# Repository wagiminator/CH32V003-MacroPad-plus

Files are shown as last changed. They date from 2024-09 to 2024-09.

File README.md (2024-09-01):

# MacroPad plus based on CH32V003
The MacroPad plus is a versatile extension for your keyboard that has six programmable keys and a rotary encoder knob. These buttons and the knob can be configured to perform a variety of actions, such as triggering specific key combinations or mouse movements. You can easily modify the firmware used to operate the MacroPad to suit your needs.

Each button and knob on the MacroPad also has addressable LEDs (NeoPixels), which can be programmed in the same way as the keys. This lets you customize the colors, patterns, or animations of your device.

Connecting the MacroPad to your PC is easy - simply plug it in via USB. It's immediately recognized by your PC as an HID composite device, so no special drivers are needed. This makes the MacroPad a user-friendly and accessible option for anyone looking to enhance their keyboard's capabilities.

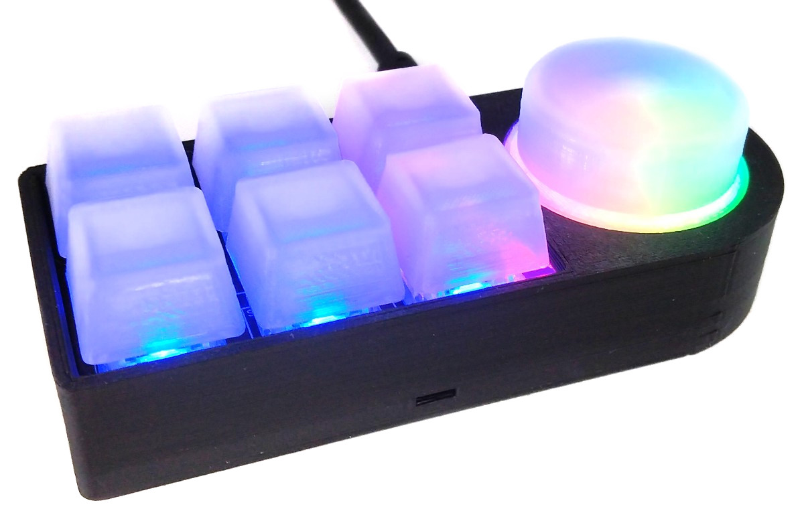
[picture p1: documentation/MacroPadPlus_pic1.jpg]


# Hardware
## Schematic
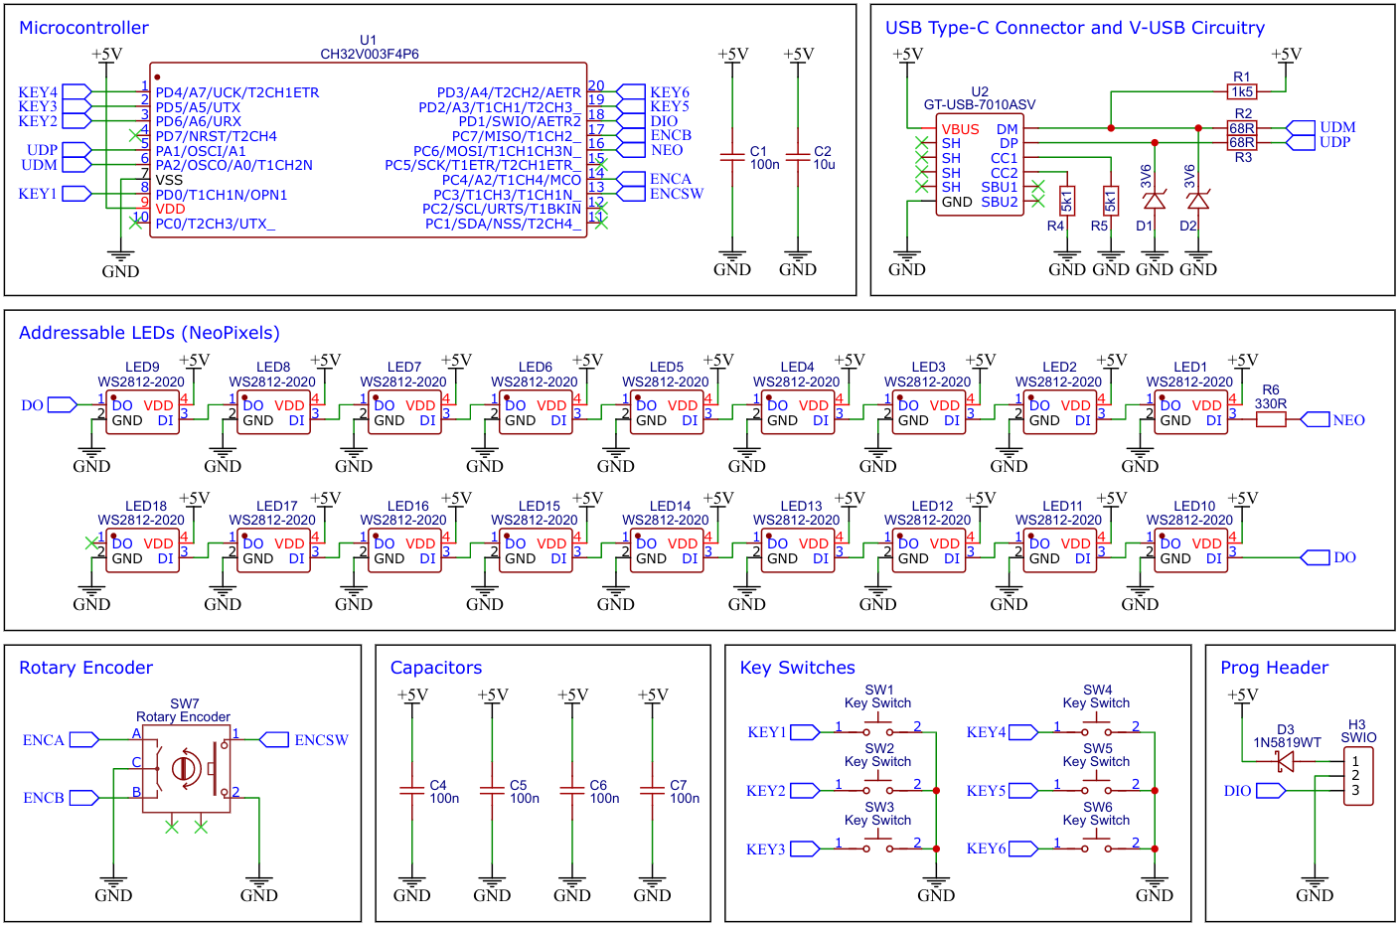
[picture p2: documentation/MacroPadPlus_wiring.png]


## The CH32V003 Family of 32-bit RISC-V Microcontrollers
The CH32V003 series is a collection of industrial-grade general-purpose microcontrollers that utilize the QingKe RISC-V2A core design supporting the RV32EC instruction set. These microcontrollers are equipped with various features such as a 48MHz system main frequency, 16KB flash, 2KB SRAM, 2.7V - 5.5V supply voltage support, a single-wire serial debug interface, low power consumption, and an ultra-small package. Additionally, the CH32V003 series includes a built-in set of components including a DMA controller, a 10-bit ADC, op-amp comparators, multiple timers, and standard communication interfaces such as USART, I2C, and SPI.

## Buildung Instructions
1. Take the Gerber files (the *zip* file inside the *hardware* folder) and upload them to a PCB (printed circuit board) manufacturer of your choice (e.g., [JLCPCB](https://jlcpcb.com/)). They will use these files to create the circuit board for your device and send it to you.
2. Once you have the PCB, you can start soldering the components onto it. Use the BOM (bill of materials) and schematic as a guide to make sure everything is connected correctly. You can find the corresponding files in the *hardware* folder.
3. Upload the firmware by following the instructions in the next section (see below).
4. To create the case for your device, use the *stl* files in the *3dprint* folder with your 3D printer. Make sure to use transparent filament for the keycaps, knob, and ring.
5. After printing, secure the PCB to the bottom of the case using three self-tapping M2x5mm screws.
6. Next, glue the ring from the bottom into the circular recess in the top of the case.
7. Finally, assemble the case. Place the keycaps onto the switches and the knob onto the rotary encoder. Your device is now ready to use!

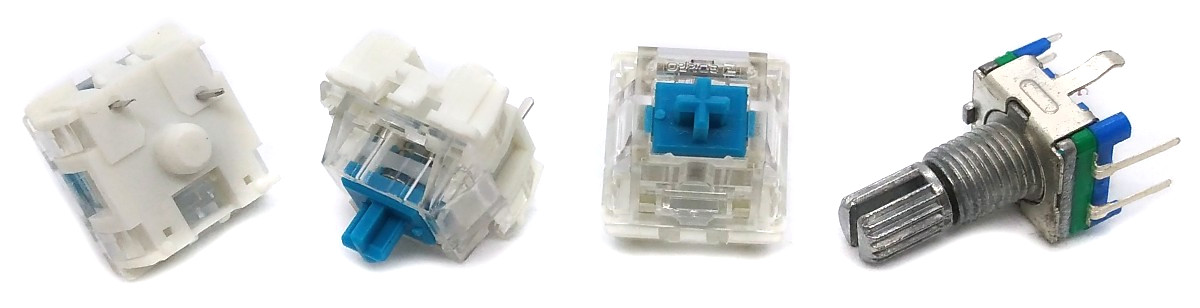
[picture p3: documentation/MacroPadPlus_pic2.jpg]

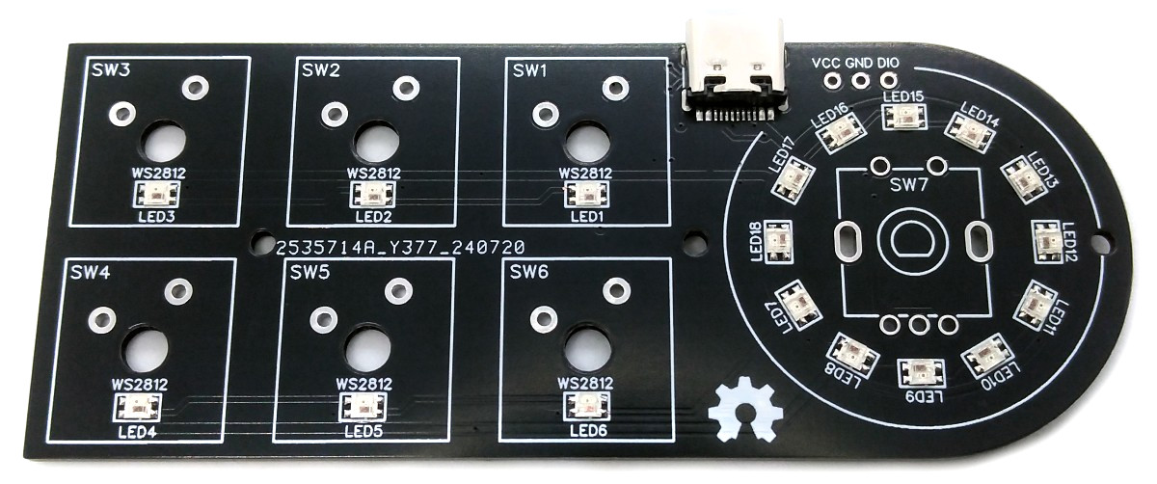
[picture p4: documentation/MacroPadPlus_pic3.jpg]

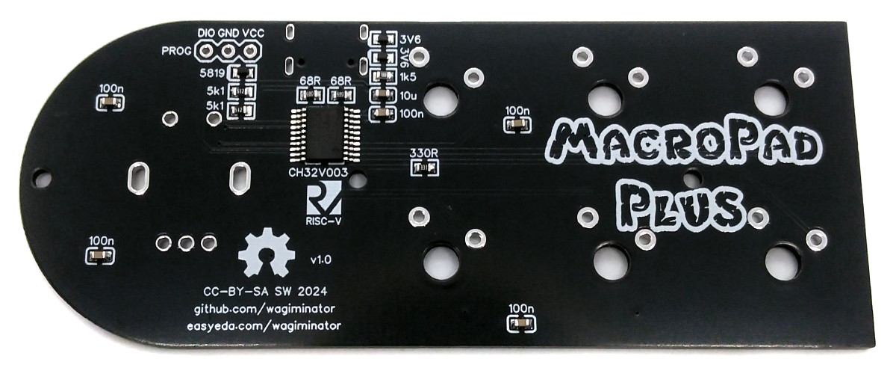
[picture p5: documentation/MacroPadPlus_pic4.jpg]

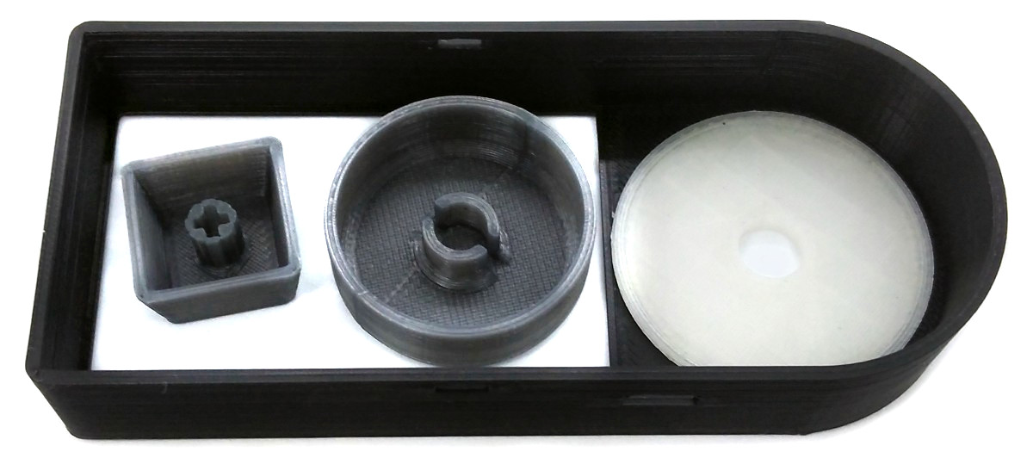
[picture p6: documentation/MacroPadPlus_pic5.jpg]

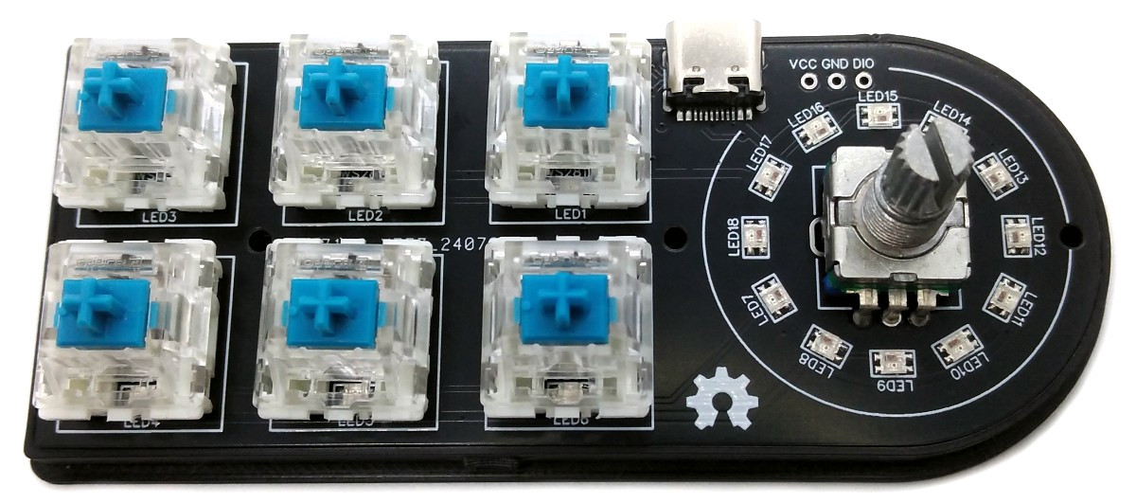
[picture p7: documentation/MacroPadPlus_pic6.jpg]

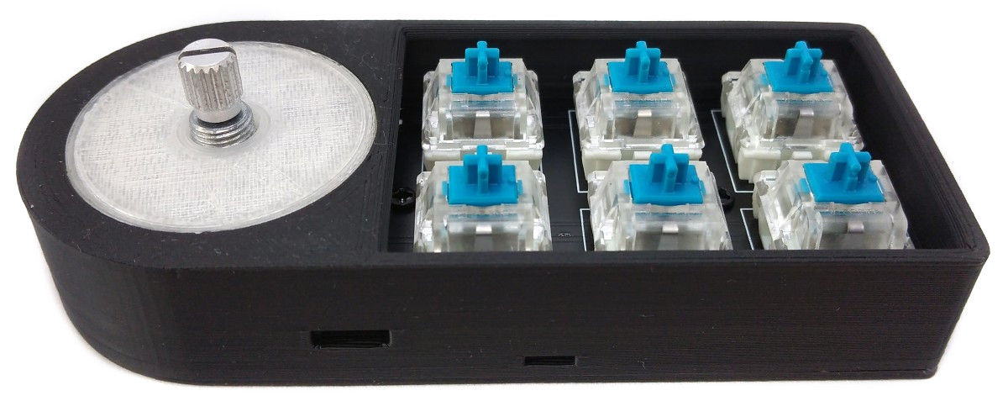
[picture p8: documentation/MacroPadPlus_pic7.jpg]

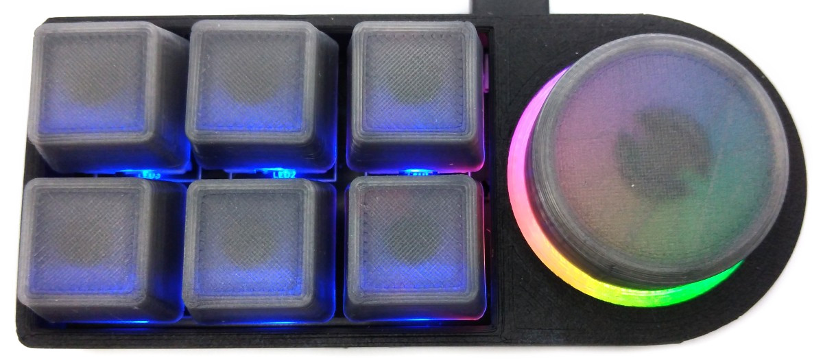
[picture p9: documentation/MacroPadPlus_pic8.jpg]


# Software
## Software USB
Since the CH32V003 lacks a hardware USB peripheral, USB functionality is handled in software. Charles Lohr's excellent implementation, [RV003USB](https://github.com/cnlohr/rv003usb), is used for this. It emulates a USB low-speed device using pin-change interrupts and bit-banging, with assembly code for the low-level protocol and some C code for higher-level functionality.

## Customizing the Firmware
The definition of the macros and their assignment to individual key events is done by editing the *macros.h* accordingly, which allows maximum freedom and flexibility. This file is commented in such a way that it should be possible to make adjustments even with basic programming skills.

## Programming and Debugging Device
To program the CH32V003 microcontroller, you will need a special programming device which utilizes the proprietary single-wire serial debug interface (SDI). The [WCH-LinkE](http://www.wch-ic.com/products/WCH-Link.html) (pay attention to the "E" in the name) is a suitable device for this purpose and can be purchased commercially for around $4. This debugging tool is not only compatible with the CH32V003 but also with other WCH RISC-V and ARM-based microcontrollers.



To use the WCH-LinkE on Linux, you need to grant access permissions beforehand by executing the following commands:
```
echo 'SUBSYSTEM=="usb", ATTR{idVendor}=="1a86", ATTR{idProduct}=="8010", MODE="666"' | sudo tee /etc/udev/rules.d/99-WCH-LinkE.rules
echo 'SUBSYSTEM=="usb", ATTR{idVendor}=="1a86", ATTR{idProduct}=="8012", MODE="666"' | sudo tee -a /etc/udev/rules.d/99-WCH-LinkE.rules
sudo udevadm control --reload-rules
```

On Windows, if you need to you can install the WinUSB driver over the WCH interface 1 using the [Zadig](https://zadig.akeo.ie/) tool.

To upload the firmware, you need to ensure that the MacoPad is disconnected from USB. Then, you should make the following connections to the WCH-LinkE:

```
WCH-LinkE      MacroPad
+-------+      +------+
|  SWDIO| <--> |DIO   |
|    GND| ---> |GND   |
|    3V3| ---> |VCC   |
+-------+      +------+
```

If the blue LED on the WCH-LinkE remains illuminated once it is connected to the USB port, it means that the device is currently in ARM mode and must be switched to RISC-V mode initially. There are a few ways to accomplish this:
- You can utilize the Python command-line tool [rvprog](https://pypi.org/project/rvprog/) (with *-v* option).
- Alternatively, you can select "WCH-LinkRV" in the software provided by WCH, such as MounRiver Studio or WCH-LinkUtility.
- Another option is to hold down the ModeS button on the device while plugging it into the USB port.

More information can be found in the [WCH-Link User Manual](http://www.wch-ic.com/downloads/WCH-LinkUserManual_PDF.html).

## Compiling and Uploading Firmware using the Makefile
### Linux
Install the toolchain (GCC compiler, Python3, and rvprog):
```
sudo apt install build-essential libnewlib-dev gcc-riscv64-unknown-elf
sudo apt install python3 python3-pip
pip install rvprog
```

Disconnect the USB cable from the MacroPad. Connect the MacroPad via the 3-pin PROG header to the WCH-LinkE programming device. Open a terminal and navigate to the folder with the *makefile*. Run the following command to compile and upload:
```
make flash
```

### Other Operating Systems
Follow the instructions on [CNLohr's ch32v003fun page](https://github.com/cnlohr/ch32v003fun/wiki/Installation) to set up the toolchain on your respective operating system (for Windows, use WSL). Also, install [Python3](https://www.pythontutorial.net/getting-started/install-python/) and [rvprog](https://pypi.org/project/rvprog/). Compile and upload with "make flash". Note that I only have Debian-based Linux and have not tested it on other operating systems.

## Uploading pre-compiled Firmware Binary
WCH offers the free but closed-source software [WCH-LinkUtility](https://www.wch.cn/downloads/WCH-LinkUtility_ZIP.html) to upload the precompiled hex-file with Windows. Select the "WCH-LinkRV" mode in the software, open the *<firmware>.hex* file in the *bin* folder and upload it to the microcontroller.

Alternatively, there is an open-source tool called [minichlink](https://github.com/cnlohr/ch32v003fun/tree/master/minichlink) developed by Charles Lohr (CNLohr). It can be used with Windows, Linux and Mac.

If you have installed [Python3](https://www.pythontutorial.net/getting-started/install-python/) on your system, you can also use the platform-independent open-source command-line tool [rvprog](https://pypi.org/project/rvprog/) for uploading:
```
rvprog -f bin/macropad_plus.bin
```

# References, Links and Notes
- [EasyEDA Design Files](https://oshwlab.com/wagiminator)
- [CNLohr: rv003usb](https://github.com/cnlohr/rv003usb)
- [MCU Templates](https://github.com/wagiminator/MCU-Templates)
- [MCU Flash Tools](https://github.com/wagiminator/MCU-Flash-Tools)
- [CH32V003 Datasheets](http://www.wch-ic.com/products/CH32V003.html)
- [CH32V003 USB Knob](https://github.com/wagiminator/CH32V003-USB-Knob)
- [CH32V003 USB Joystick](https://github.com/wagiminator/CH32V003-USB-Joystick)
- [CH552E USB Knob](https://github.com/wagiminator/CH552-USB-Knob)
- [CH552E MacroPad mini](https://github.com/wagiminator/CH552-Macropad-mini)
- [CH552G MacroPad plus](https://github.com/wagiminator/CH552-MacroPad-plus)
- [ATtiny85 TinyKnob](https://github.com/wagiminator/ATtiny85-TinyKnob)

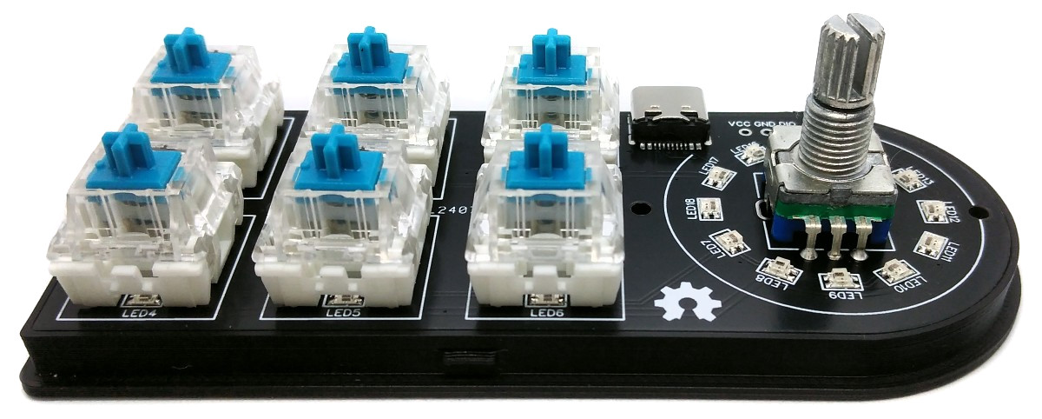
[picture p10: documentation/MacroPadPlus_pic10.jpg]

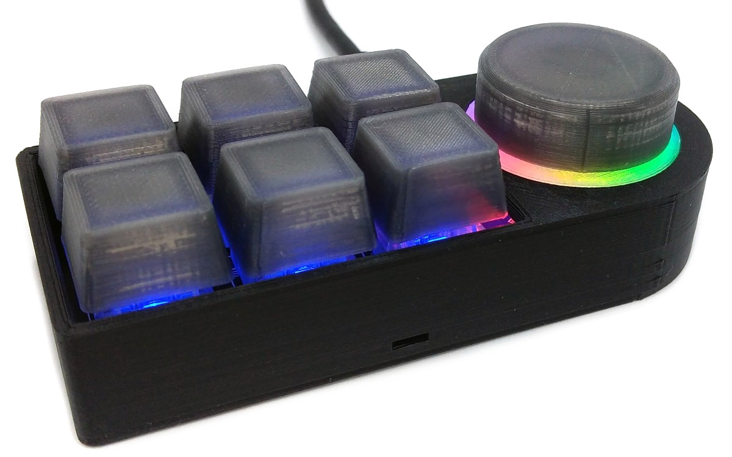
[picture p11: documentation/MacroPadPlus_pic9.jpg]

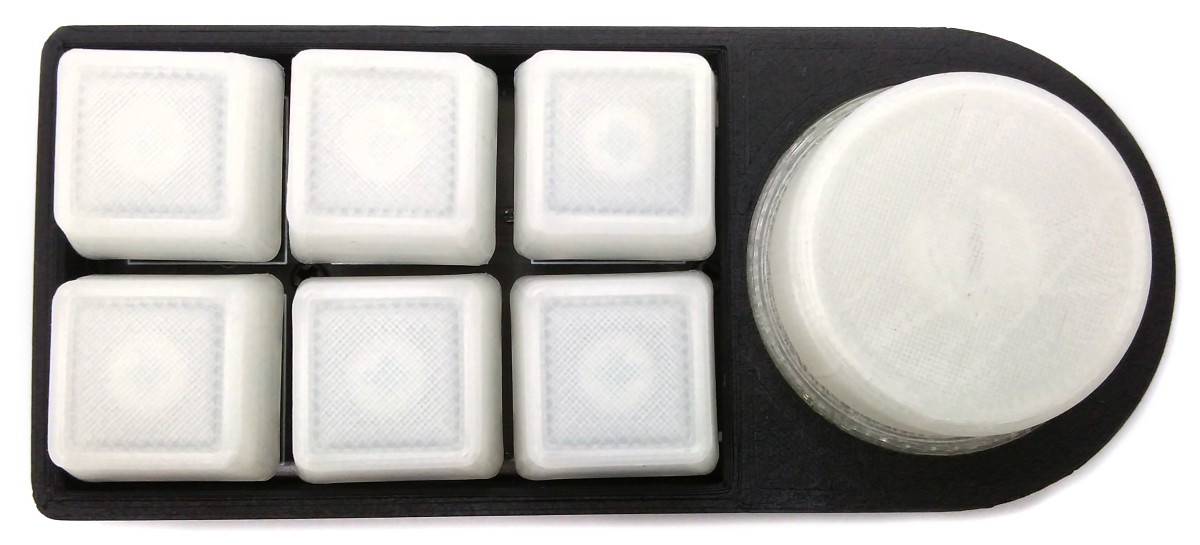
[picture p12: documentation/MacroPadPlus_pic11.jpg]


# License


This work is licensed under Creative Commons Attribution-ShareAlike 3.0 Unported License. 
(http://creativecommons.org/licenses/by-sa/3.0/)

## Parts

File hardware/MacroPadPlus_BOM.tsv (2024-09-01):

ID | Name | Designator | Footprint | Quantity | Manufacturer Part | Manufacturer | Supplier | Supplier Part
1 | 100n | C1,C4,C5,C6,C7 | C_0603 | 5 | CC0603KRX7R9BB104 | YAGEO | LCSC | C14663
2 | 10u | C2 | C_0603 | 1 | CL10A106KP8NNNC | SAMSUNG | LCSC | C19702
3 | 3V6 | D1,D2 | SOD-523 | 2 | LM5Z3V6T1G | LRC(乐山无线电) | LCSC | C111055
4 | 1N5819WT | D3 | SOD-523 | 1 | 1N5819WT | Slkor(萨科微) | LCSC | C5185918
5 | SWIO | H3 | 210S-3X1/2.54 | 1 | Header2.54mm 1*3P | BOOMELE | LCSC | C49257
6 | WS2812-2020 | LED1,LED2,LED3,LED4,LED5,LED6,LED7,LED8,LED9,LED10,LED11,LED12,LED13,LED14,LED15,LED16,LED17,LED18 | WS2812-2020 | 18 | WS2812C-2020-V1 | worldsemi | LCSC | C2976072
7 | 1k5 | R1 | 0603 | 1 | 0603WAF1501T5E | UniOhm | LCSC | C22843
8 | 68R | R2,R3 | 0603 | 2 | 0603WAF680JT5E | UniOhm | LCSC | C27592
9 | 5k1 | R4,R5 | 0603 | 2 | 0603WAF5101T5E | UNI-ROYAL(厚声) | LCSC | C23186
10 | 330R | R6 | 0603 | 1 | 0603WAF3300T5E | UniOhm | LCSC | C23138
11 | Key Switch | SW1,SW2,SW3,SW4,SW5,SW6 | KEY-TH | 6 | CPG151101D213 | Kailh(凯华) | LCSC | C400235
12 | Rotary Encoder | SW7 | ROTARY_ENCODER | 1 | PEC11R-4015F-S0024 | BOURNS | LCSC | C143789
13 | CH32V003F4P6 | U1 | TSSOP-20 | 1 | CH32V003F4U6 | WCH |  | C5299908
14 | GT-USB-7010ASV | U2 | USB-C-7010ASV-SX | 1 | GT-USB-7010ASV | G-Switch(品赞) | LCSC | C2988369

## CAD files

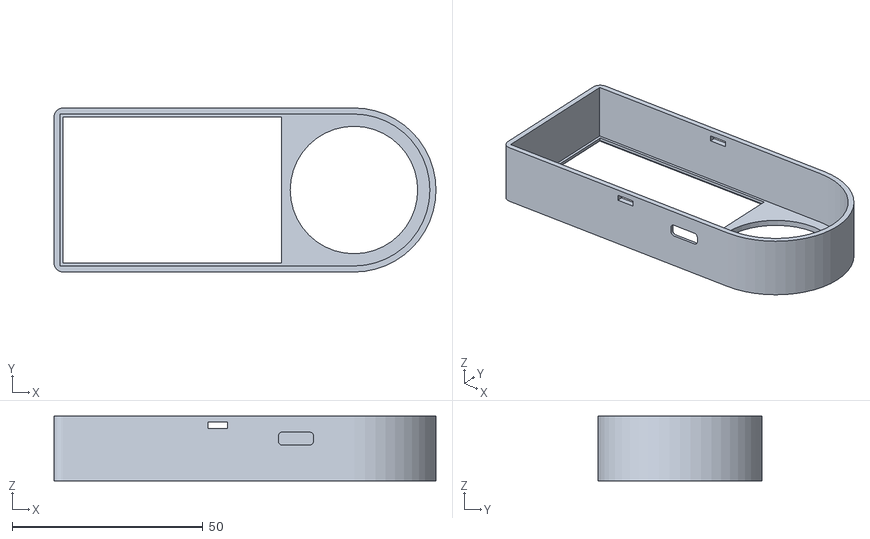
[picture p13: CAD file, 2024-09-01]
3dprint/MacroPadPlus_case_top.stl
100.1 x 43.0 x 17.0

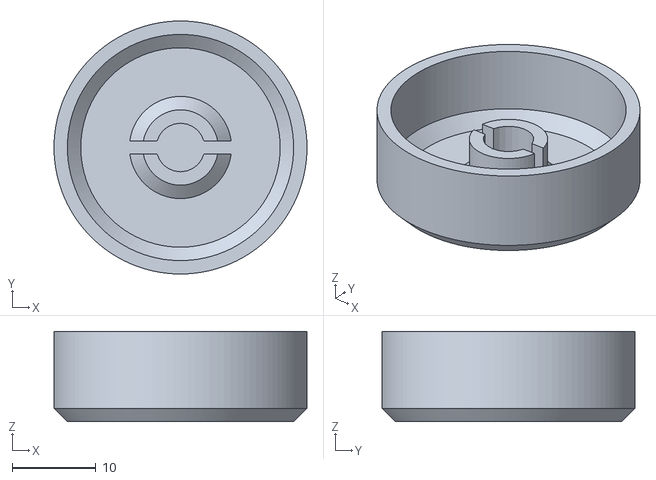
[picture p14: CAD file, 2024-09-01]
3dprint/MacroPadPlus_knob.stl
30.2 x 30.2 x 10.8

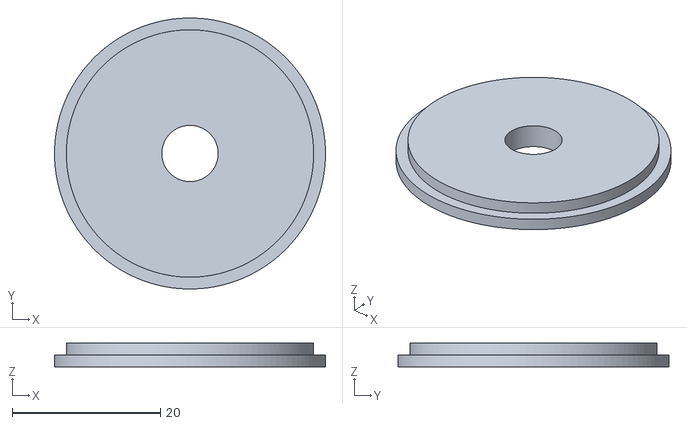
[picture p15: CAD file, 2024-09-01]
3dprint/MacroPadPlus_ring.stl
36.6 x 36.6 x 3.20

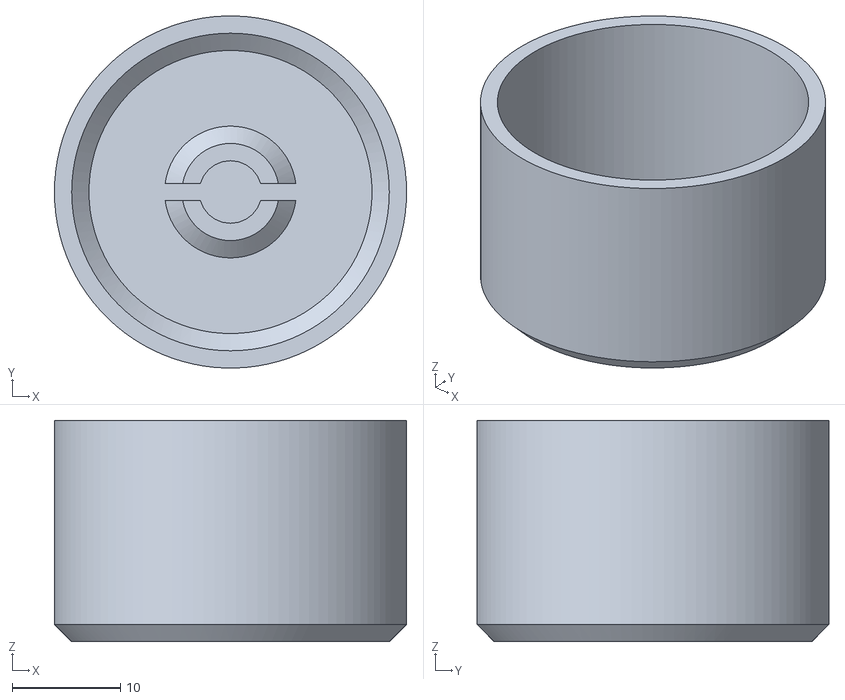
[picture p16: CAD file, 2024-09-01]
3dprint/MacroPadPlus_knob_big.stl
32.6 x 32.6 x 20.5

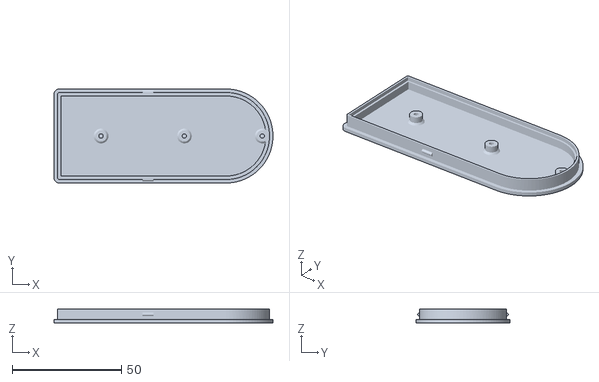
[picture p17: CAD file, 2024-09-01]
3dprint/MacroPadPlus_case_bottom.stl
100.1 x 43.0 x 6.60

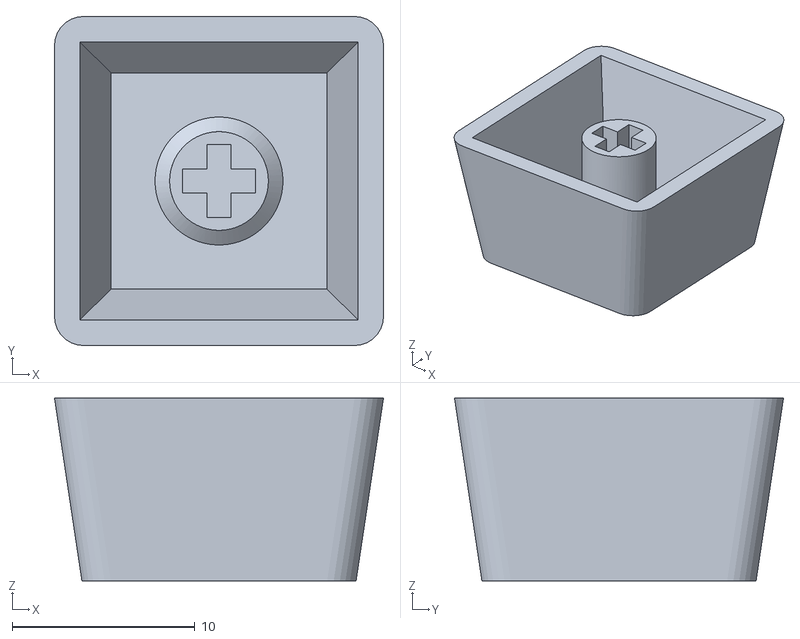
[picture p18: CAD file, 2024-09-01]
3dprint/MacroPadPlus_keycap.stl
18.0 x 18.0 x 10.0

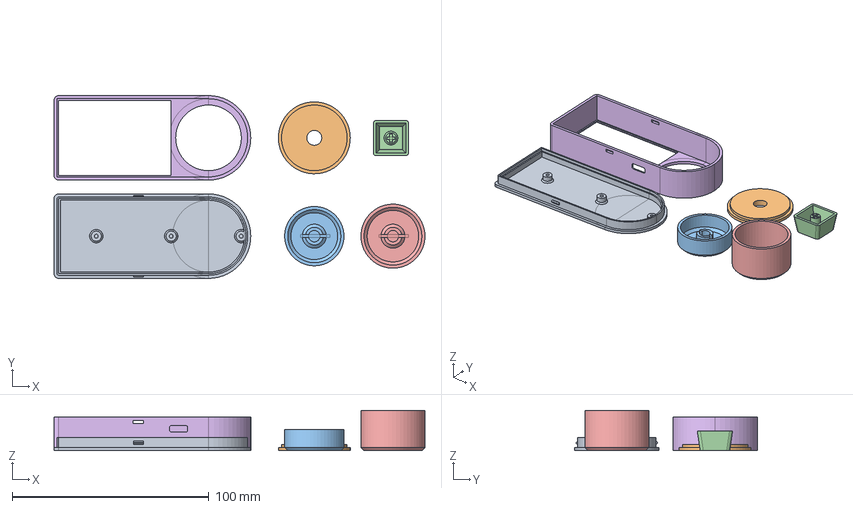
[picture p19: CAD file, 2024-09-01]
3dprint/MacroPadPlus_case.FCStd
188.7 x 93.0 x 20.5 mm
Bottom
Ring
Knob
Keycap
Knob_big
Top

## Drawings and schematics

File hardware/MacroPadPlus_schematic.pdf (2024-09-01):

Microcontroller | USB Type-C Connector and V-USB Circuitry 5k1

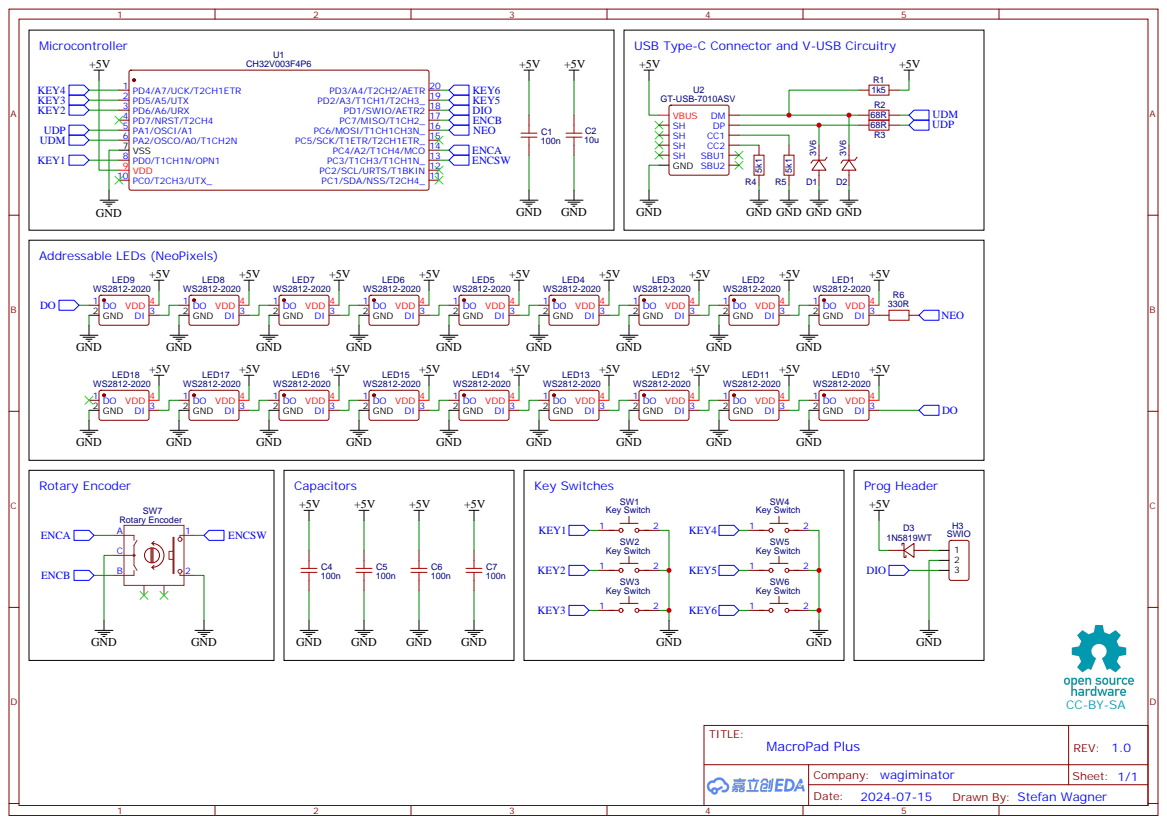
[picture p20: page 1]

Drawn By: Stefan Wagner

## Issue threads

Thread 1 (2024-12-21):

Does it work on windows OS?

hina1929, 2024-12-21:
I created this ch32bv003-macropad plus using publicly available data but it does not work well on windowsOS.
 It works fine on chromeOS.
 Does this not work on windows OS? Or do I need to do something?
Translated by Deepl

wagiminator, 2024-12-23:
What do you mean by "not well"? It should normally work with any operating system since HID is a standard. However, I don't have a Windows PC myself, so unfortunately, I can't help you further at the moment.

hina1929, 2024-12-23:
Thanks for the reply.
 The rotary encoder only responds once every few times.
 As for the keyswitches, they are not responsive at all.
 I tried the media keys, modifier keys, and regular letters, but none of them responded.
 I thought it might be a slow process, so I implemented the "Mouse Wiggler" from your repository on a universal board and tried it on the windows PC in question, and it worked fine.

wagiminator, 2024-12-23:
When I have access to a Windows PC again, I'll run some tests.

hina1929, 2024-12-23:
Thank you so much.

Closed 2024-12-23.

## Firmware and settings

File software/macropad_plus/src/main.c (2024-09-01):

// ===================================================================================
// Project:   MacroPad Plus for CH32V003
// Version:   v1.0
// Year:      2024
// Author:    Stefan Wagner
// Github:    https://github.com/wagiminator
// EasyEDA:   https://easyeda.com/wagiminator
// License:   http://creativecommons.org/licenses/by-sa/3.0/
// ===================================================================================
//
// Description:
// ------------
// Firmware example implementation for the MacroPad Plus.
//
// References:
// -----------
// - CNLohr ch32v003fun: https://github.com/cnlohr/ch32v003fun
// - WCH Nanjing Qinheng Microelectronics: http://wch.cn
//
// Compilation Instructions:
// -------------------------
// - Make sure GCC toolchain (gcc-riscv64-unknown-elf, newlib) and Python3 with
//   rvprog (via pip) are installed. In addition, Linux requires access rights to
//   WCH-LinkE programmer.
// - Connect the WCH-LinkE programmer to the MCU board.
// - Run 'make flash'.
//
// Operating Instructions:
// -----------------------
// - Connect the board via USB to your PC. It should be detected as a HID device with
//   keyboard and mouse interface.
// - Press a macro key or turn the knob and see what happens.


// ===================================================================================
// Libraries, Definitions and Macros
// ===================================================================================
#include <config.h>                               // user configurations
#include <system.h>                               // system functions
#include <gpio.h>                                 // GPIO functions
#include <neo_spi.h>                              // NeoPixel fuctions
#include <encoder_tim.h>                          // rotary encoder functions
#include <usb_composite.h>                        // USB HID composite functions
#include <macros.h>                               // user defined macros

// ===================================================================================
// NeoPixel Functions
// ===================================================================================

uint8_t neoencoder = 0;                           // state of NeoPixel ring rotation

// Update NeoPixel ring colors
void NEO_encoder_update(void) {
  uint8_t i, j;
  j = neoencoder;
  for(i=6; i<18; i++) {
    NEO_writeHue(i, j, NEO_BRIGHT_ENC);
    j += 16;
    if(j >= 192) j -= 192;
  }
  NEO_update();
}

// Rotate NeoPixel ring clockwise
void NEO_encoder_cw(void) {
  neoencoder += 8;
  if(neoencoder >= 192) neoencoder -= 192;
  NEO_encoder_update();
}

// Rotate NeoPixel ring counter-clockwise
void NEO_encoder_ccw(void) {
  neoencoder -= 8;
  if(neoencoder >= 192) neoencoder -= 64;
  NEO_encoder_update();
}

// ===================================================================================
// Main Function
// ===================================================================================
int main(void) {
  // Variables
  uint8_t key1last = 0;                           // last state of key 1
  uint8_t key2last = 0;                           // last state of key 2
  uint8_t key3last = 0;                           // last state of key 3
  uint8_t key4last = 0;                           // last state of key 4
  uint8_t key5last = 0;                           // last state of key 5
  uint8_t key6last = 0;                           // last state of key 6
  uint8_t isSwitchPressed = 0;                    // state of rotary encoder switch

  // Setup pins for keys and encoder
  PIN_input_PU(PIN_KEY1);
  PIN_input_PU(PIN_KEY2);
  PIN_input_PU(PIN_KEY3);
  PIN_input_PU(PIN_KEY4);
  PIN_input_PU(PIN_KEY5);
  PIN_input_PU(PIN_KEY6);
  PIN_input_PU(PIN_ENC_SW);
  PIN_input_PU(PIN_ENC_A);
  PIN_input_PU(PIN_ENC_B);

  // Setup NeoPixels
  NEO_init();                                     // init NeoPixels
  NEO_clearAll();                                 // clear NeoPixels

  // Init USB HID device
  HID_init();                                     // init USB HID device
  NEO_encoder_update();                           // set NeoPixel ring for encoder

  // Loop
  while(1) {

    // Handle key 1
    // ------------
    if((!PIN_read(PIN_KEY1)) != key1last) {       // key state changed?
      key1last = !key1last;                       // update last state flag
      if(key1last) {                              // key was pressed?
        NEO_writeHue(0, NEO_KEY1, NEO_BRIGHT_KEYS);    // light up corresponding NeoPixel
        NEO_update();                             // update pixels
        KEY1_PRESSED();                           // take proper action
      }
      else {                                      // key was released?
        NEO_clearPixel(0);                        // light up corresponding NeoPixel
        NEO_update();                             // update pixels
        KEY1_RELEASED();                          // take proper action
      }
    }
    else if(key1last) {                           // key still being pressed?
      KEY1_HOLD();                                // take proper action
    }

    // Handle key 2
    // ------------
    if((!PIN_read(PIN_KEY2)) != key2last) {       // key state changed?
      key2last = !key2last;                       // update last state flag
      if(key2last) {                              // key was pressed?
        NEO_writeHue(1, NEO_KEY2, NEO_BRIGHT_KEYS);    // light up corresponding NeoPixel
        NEO_update();                             // update pixels
        KEY2_PRESSED();                           // take proper action
      }
      else {                                      // key was released?
        NEO_clearPixel(1);                        // light up corresponding NeoPixel
        NEO_update();                             // update pixels
        KEY2_RELEASED();                          // take proper action
      }
    }
    else if(key2last) {                           // key still being pressed?
      KEY2_HOLD();                                // take proper action
    }

    // Handle key 3
    // ------------
    if((!PIN_read(PIN_KEY3)) != key3last) {       // key state changed?
      key3last = !key3last;                       // update last state flag
      if(key3last) {                              // key was pressed?
        NEO_writeHue(2, NEO_KEY3, NEO_BRIGHT_KEYS);    // light up corresponding NeoPixel
        NEO_update();                             // update pixels
        KEY3_PRESSED();                           // take proper action
      }
      else {                                      // key was released?
        NEO_clearPixel(2);                        // light up corresponding NeoPixel
        NEO_update();                             // update pixels
        KEY3_RELEASED();                          // take proper action
      }
    }
    else if(key3last) {                           // key still being pressed?
      KEY3_HOLD();                                // take proper action
    }

    // Handle key 4
    // ------------
    if((!PIN_read(PIN_KEY4)) != key4last) {       // key state changed?
      key4last = !key4last;                       // update last state flag
      if(key4last) {                              // key was pressed?
        NEO_writeHue(3, NEO_KEY4, NEO_BRIGHT_KEYS);    // light up corresponding NeoPixel
        NEO_update();                             // update pixels
        KEY4_PRESSED();                           // take proper action
      }
      else {                                      // key was released?
        NEO_clearPixel(3);                        // light up corresponding NeoPixel
        NEO_update();                             // update pixels
        KEY4_RELEASED();                          // take proper action
      }
    }
    else if(key4last) {                           // key still being pressed?
      KEY4_HOLD();                                // take proper action
    }

    // Handle key 5
    // ------------
    if((!PIN_read(PIN_KEY5)) != key5last) {       // key state changed?
      key5last = !key5last;                       // update last state flag
      if(key5last) {                              // key was pressed?
        NEO_writeHue(4, NEO_KEY5, NEO_BRIGHT_KEYS);    // light up corresponding NeoPixel
        NEO_update();                             // update pixels
        KEY5_PRESSED();                           // take proper action
      }
      else {                                      // key was released?
        NEO_clearPixel(4);                        // light up corresponding NeoPixel
        NEO_update();                             // update pixels
        KEY5_RELEASED();                          // take proper action
      }
    }
    else if(key5last) {                           // key still being pressed?
      KEY5_HOLD();                                // take proper action
    }

    // Handle key 6
    // ------------
    if((!PIN_read(PIN_KEY6)) != key6last) {       // key state changed?
      key6last = !key6last;                       // update last state flag
      if(key6last) {                              // key was pressed?
        NEO_writeHue(5, NEO_KEY6, NEO_BRIGHT_KEYS);    // light up corresponding NeoPixel
        NEO_update();                             // update pixels
        KEY6_PRESSED();                           // take proper action
      }
      else {                                      // key was released?
        NEO_clearPixel(5);                        // light up corresponding NeoPixel
        NEO_update();                             // update pixels
        KEY6_RELEASED();                          // take proper action
      }
    }
    else if(key6last) {                           // key still being pressed?
      KEY6_HOLD();                                // take proper action
    }

    // Handle rotary encoder
    // ---------------------
    if(!PIN_read(PIN_ENC_A)) {                    // encoder turned ?
      if(PIN_read(PIN_ENC_B)) {                   // clockwise ?
        ENC_CW_ACTION();                          // take proper action
        NEO_encoder_cw();                         // rotate NeoPixels
        DLY_ms(5);                                // debounce
        ENC_CW_RELEASED();                        // take proper action
      }
      else {                                      // counter-clockwise ?
        ENC_CCW_ACTION();                         // take proper action
        NEO_encoder_ccw();                        // rotate NeoPixels
        DLY_ms(5);                                // debounce
        ENC_CCW_RELEASED();                       // take proper action
      }
      while(!PIN_read(PIN_ENC_A));                // wait until next detent
    } 
    else {
      if(!isSwitchPressed && !PIN_read(PIN_ENC_SW)) {     // switch previously pressed?
        ENC_SW_PRESSED();                         // take proper action
        isSwitchPressed = 1;
      }
      else if(isSwitchPressed && PIN_read(PIN_ENC_SW)) {  // switch previously released?
        ENC_SW_RELEASED();                        // take proper action
        isSwitchPressed = 0;                      // update switch state
      }
    }

    DLY_ms(1);                                    // debounce
  }
}

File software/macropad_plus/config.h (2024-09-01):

// ===================================================================================
// CH32V003 MacroPad Plus User Configurations
// ===================================================================================

#pragma once

// Pin defines
#define PIN_KEY1            PD0       // connected to key 1 (active low)
#define PIN_KEY2            PD6       // connected to key 2 (active low)
#define PIN_KEY3            PD5       // connected to key 3 (active low)
#define PIN_KEY4            PD4       // connected to key 4 (active low)
#define PIN_KEY5            PD2       // connected to key 5 (active low)
#define PIN_KEY6            PD3       // connected to key 6 (active low)
#define PIN_ENC_A           PC4       // connected to rotary encoder A (do not change!)
#define PIN_ENC_B           PC7       // connected to rotary encoder B (do not change!)
#define PIN_ENC_SW          PC3       // connected to rotary encoder switch
#define PIN_NEO             PC6       // connected to NeoPixels (do not change!)

// USB pin definitions
#define USB_PORT            A         // [A,C,D] GPIO Port to use with D+, D- and DPU
#define USB_PIN_DP          1         // [0-4] GPIO Number for USB D+ Pin
#define USB_PIN_DM          2         // [0-4] GPIO Number for USB D- Pin

// USB configuration descriptor
#define USB_MAX_POWER_mA    50        // max power in mA 

// USB device descriptor
#define USB_VENDOR_ID       0x1209    // VID
#define USB_PRODUCT_ID      0xc003    // PID
#define USB_DEVICE_VERSION  0x0100    // v1.0 (BCD-format)
#define USB_LANGUAGE        0x0409    // US English

// USB string descriptors
#define MANUF_STR           "wagiminator"
#define PROD_STR            "MacroPad Plus"
#define SERIAL_STR          "CH32V003HID"
